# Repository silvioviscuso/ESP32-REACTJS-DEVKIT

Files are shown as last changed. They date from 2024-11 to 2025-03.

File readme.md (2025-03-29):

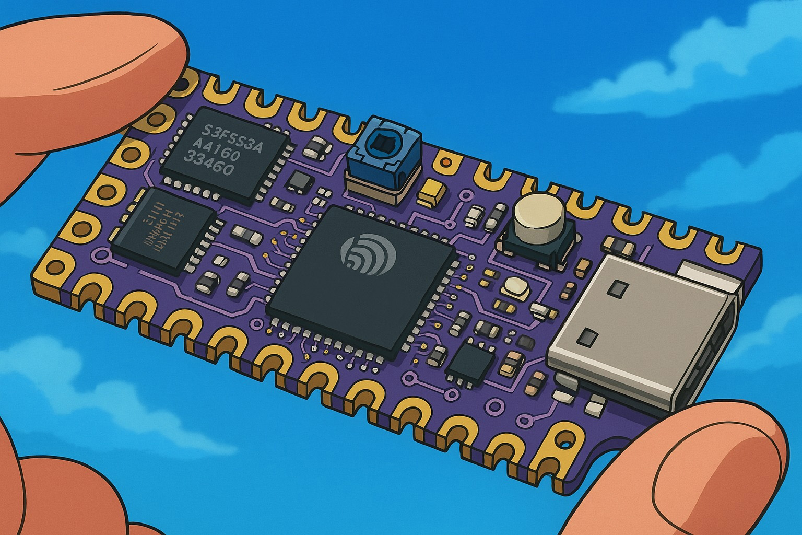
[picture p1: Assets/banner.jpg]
ESP32-REACTJS-DEVKIT


# ESP32-REACTJS-DEVKIT

## 📖 Description
**ESP32-REACTJS-DEVKIT** is an ultra-compact board based on **ESP32-D0WDQ6** with **16MB of Flash RAM**, designed for **robotics, IoT, and wearable** applications. Thanks to its small size and the power of the ESP32, it is ideal for advanced projects requiring wireless connectivity and high computational performance.

### 📏 Dimensions
- **Width:** 35mm  
- **Height:** 18mm  
- **Thickness:** 1mm  

## ⭐ Main Features
- **Microcontroller:** ESP32-D0WDQ6
- **Flash Memory:** 16MB
- **Wi-Fi & Bluetooth:** Dual-mode Wi-Fi and Bluetooth 4.2 BLE
- **Ultra-compact size**, ideal for embedded projects
- **High performance** for advanced applications
- **Support for ESP-IDF and Arduino Framework**

## 🔧 Applications
- **🤖 Robotic Projects**: Motor control, sensors, and actuators with remote connectivity
- **🌐 IoT (Internet of Things)**: Smart home, industrial automation, environmental monitoring
- **⌚ Wearable Devices**: Fitness, health, and human interaction devices

---
## Preview
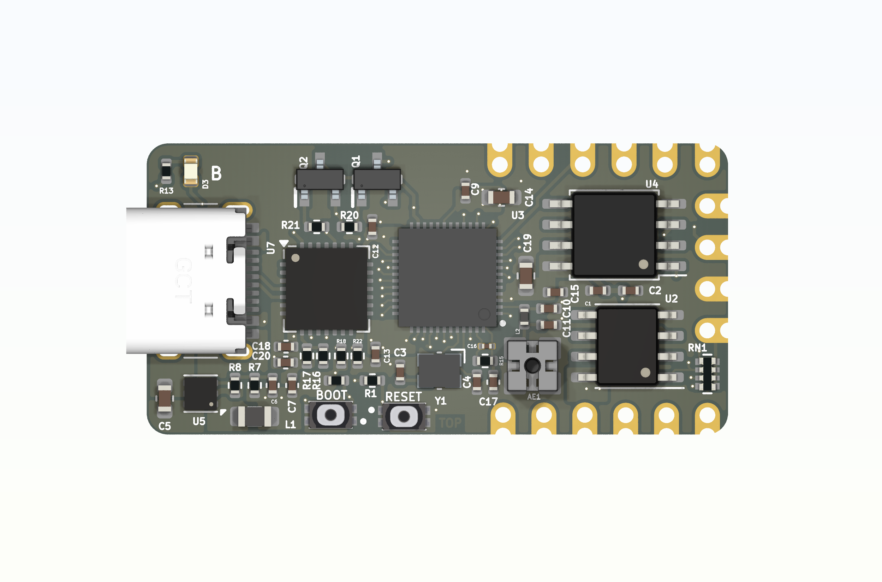
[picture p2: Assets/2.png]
Preview 2

---

## 🛠️ Requirements
- **Software**:
  - ESP-IDF (Espressif IoT Development Framework)
  - Arduino IDE (optional)
  - ReactJS for the frontend management interfaces
- **Hardware**:
  - ESP32-REACTJS-DEVKIT
  - Connection cables
  - Optional sensors and actuators

## 🏗️ Installation
### 1. 🖥️ Development Environment Setup
A **boilerplate** will soon be available to seamlessly integrate with the board. Stay tuned for updates!

### 2. 🌍 ReactJS Frontend Setup
A **dedicated boilerplate** for the ReactJS frontend is in development and will be released soon to simplify integration with the board.

## 🤝 Contributions
If you wish to contribute to the project, feel free to submit a Pull Request or report any issues in the Issues section.

## 📜 License
This project is released under the **MIT** license. You are free to use it with the obligation to credit the original authors.

---

Thank you for choosing **ESP32-REACTJS-DEVKIT**! 🚀

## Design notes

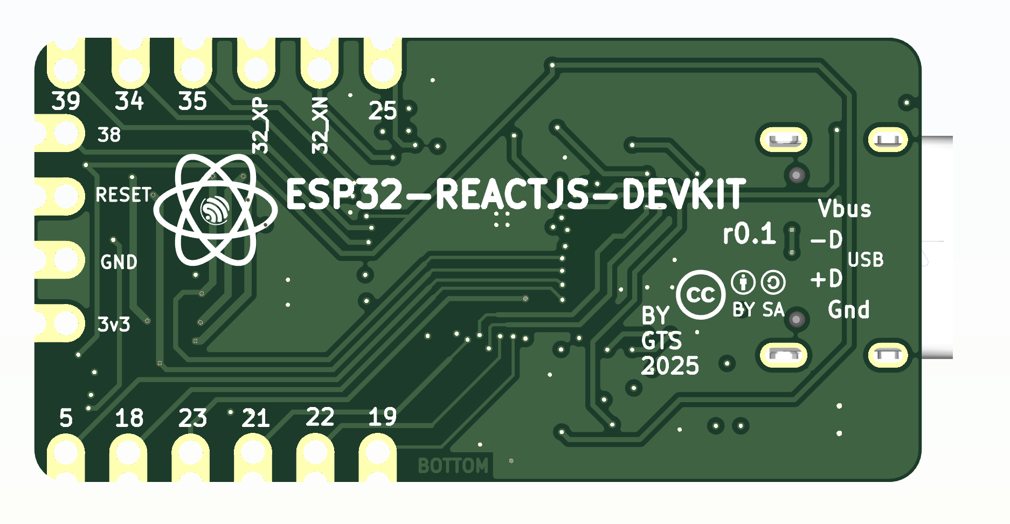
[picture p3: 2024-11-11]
Assets/Preview 2024-11-06 alle 11.08.45.png

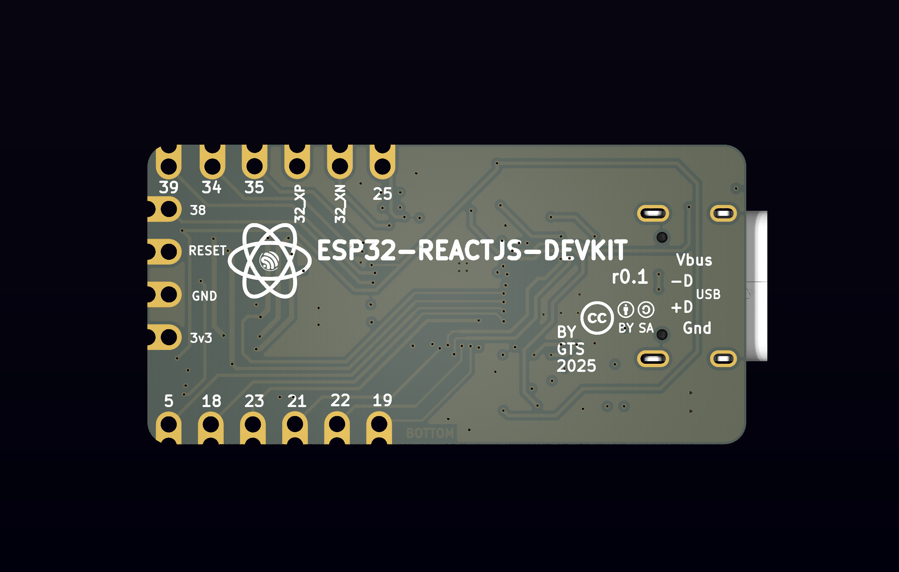
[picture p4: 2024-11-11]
Assets/Preview 2024-11-06 alle 11.10.00.png

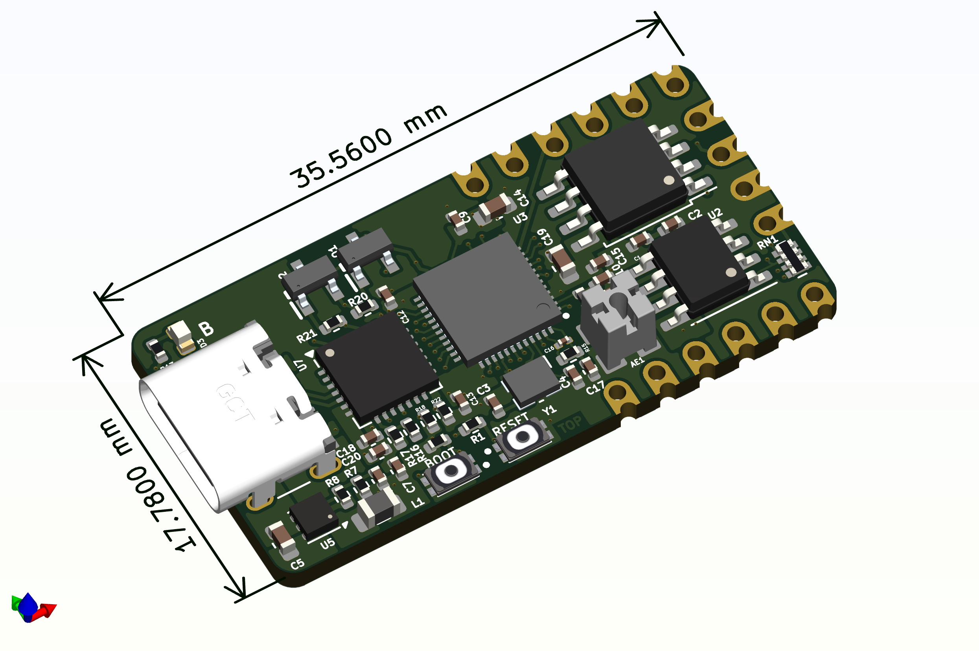
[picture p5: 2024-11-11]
Assets/Preview 2024-11-06 alle 11.07.49.png

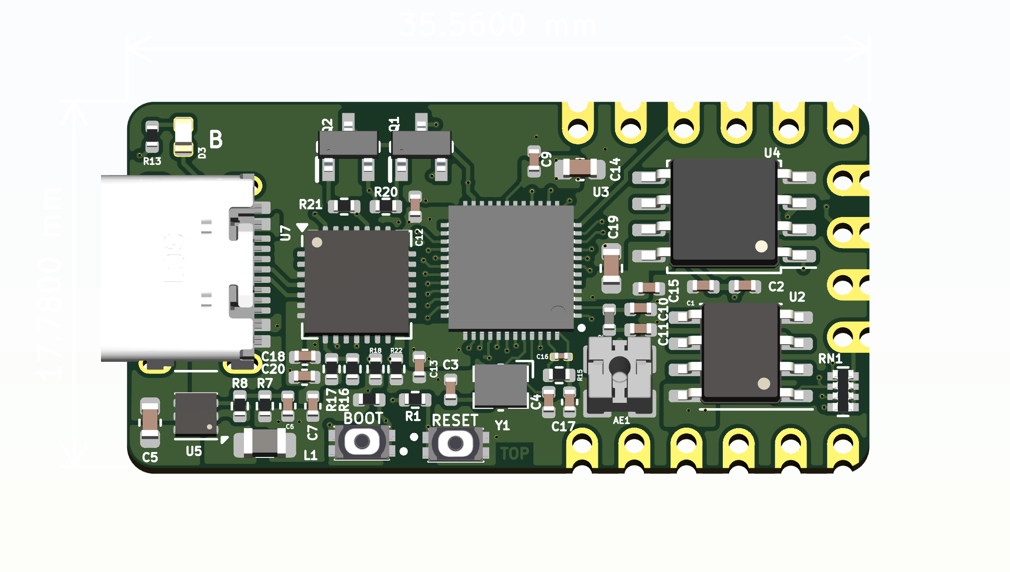
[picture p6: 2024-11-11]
Assets/Preview 2024-11-06 alle 10.54.00.png

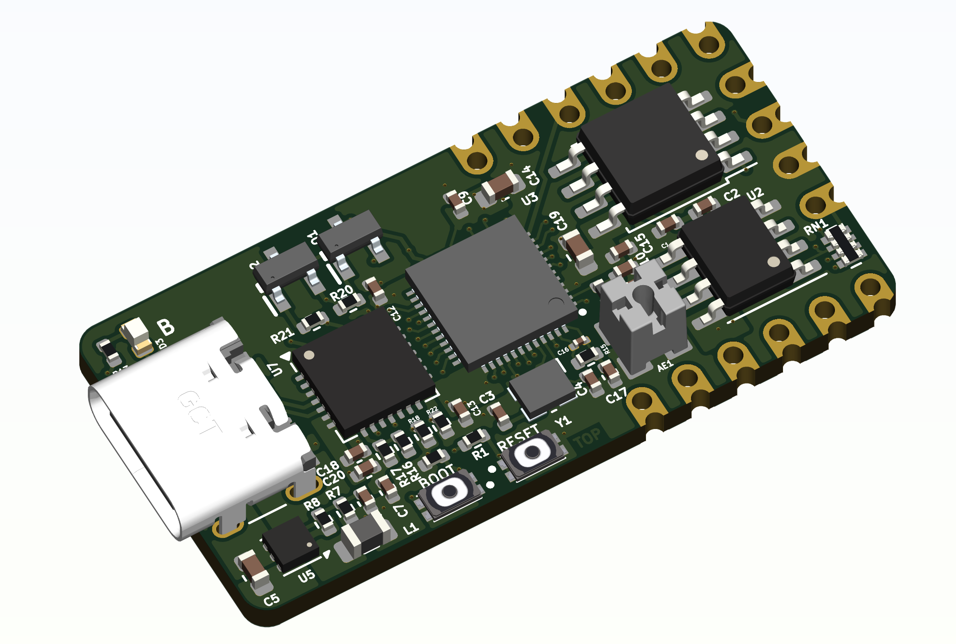
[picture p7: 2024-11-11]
Assets/Preview 2024-11-06 alle 11.07.58.png

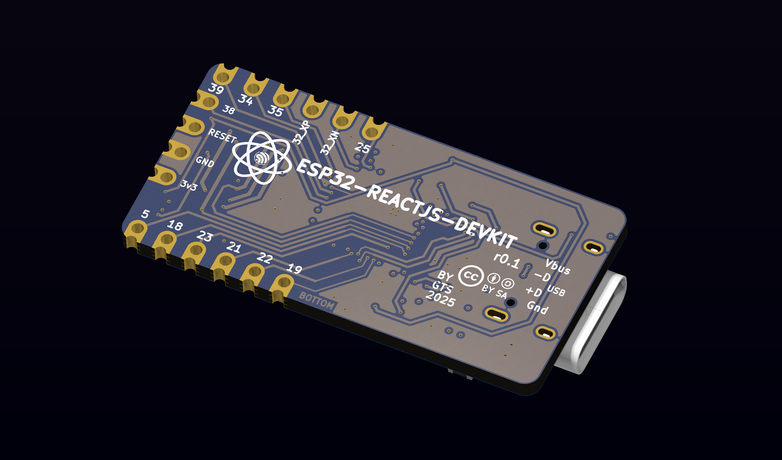
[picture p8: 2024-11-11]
Assets/Preview 2024-11-06 alle 11.17.09.png

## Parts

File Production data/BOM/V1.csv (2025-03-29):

Designator | Value | Footprint | Qty | Mfg | PN | JLCPCB part#
AE1 | Antenna | obsidian-boa:479480001 | 1 | Molex | 479480001 | C152351
C1,C2,C7 | 2.2uF | C_0402_1005Metric | 3 | Yageo | CC0402MRX5R5BB225 | C106860
C3,C4 | 18pF | Capacitor_SMD:C_0402_1005Metric | 2 | Yageo | CC0402GRNPO9BN180 | C114393
C5,C14,C19 | 10u | Capacitor_SMD:C_0603_1608Metric | 3 | Yageo | CC0603KRX5R5BB106 | C109455
C6 | 22pF | Capacitor_SMD:C_0402_1005Metric | 1 | Yageo | CC0402KRNPO9BN220 | C2168187
C9,C12,C13,C15 | 100n | Capacitor_SMD:C_0402_1005Metric | 4 | Yageo | CC0402ZRY5V7BB104 | C106209
C10,C11 | 1pF | Capacitor_SMD:C_0402_1005Metric | 2 |  | CQ0402CRNPO9BN1R0 | C1550
C16 | 3.3nF | Capacitor_SMD:C_0201_0603Metric | 1 | Yageo | GRM033R70J332KA01D | C312053
C17 | 10nF | Capacitor_SMD:C_0402_1005Metric | 1 | Yageo | KGM05AR70J103KH | C60133
C18 | 0.1uF | Capacitor_SMD:C_0402_1005Metric | 1 | Yageo | CL05B104KP5NNNC | C133086
C20 | 4.7uF | Capacitor_SMD:C_0402_1005Metric | 1 | Yageo | CL05A475MP5NRNC | C23733
D3 | BLU | obsidian-boa:LED_0603_1608Metric_Compact | 1 | Lite-On Inc. | LTST-C191TBKT | C99290
J1 | USB_C | V1-foot:USB_C_Receptacle_HRO_TYPE-C-31-M-12 | 1 | GCT | USB4105-GF-A | C3025063
L1 | 2.2uH | Inductor_SMD:L_0805_2012Metric | 1 |  | CWCI0805F-100KT | C1043
L2 | 2.7nH | Inductor_SMD:L_0402_1005Metric | 1 |  | SDCL1005C2N7STDF | C27123
Q1,Q2 | SS8050-G | SOT95P240X115-3N | 2 |  | SS8050-G | C164885
RN1 | 10K | Resistor_SMD:R_Array_Convex_4x0402 | 1 |  |  | C178757
R1,R10 | 10k | Resistor_SMD:R_0402_1005Metric | 3 | -- mixed values -- | -- mixed values -- | C60490
R7 | 453k | Resistor_SMD:R_0402_1005Metric | 1 | Yageo | RC0402FR-07453KL | C137978
R8 | 100k | Resistor_SMD:R_0402_1005Metric | 1 | Yageo | RC0402FR-07100KL | C60491
R13 | 2k2 | Resistor_SMD:R_0402_1005Metric | 1 | Yageo | RC0402FR-072K2L | C114762
R15 | 20K | Resistor_SMD:R_0402_1005Metric | 1 | Yageo | RC0402FR-0720KL | C93942
R16 | 22.1K | Resistor_SMD:R_0402_1005Metric | 1 | Yageo | CRCW040222K1FKEDC | C43473
R17 | 47.5K | Resistor_SMD:R_0402_1005Metric | 1 | Yageo | RC0402FR-0747K5L | C137974
R18 | 2K | Resistor_SMD:R_0402_1005Metric | 1 | Yageo | ERJ-2RKF2001X | C413086
R20,R21,R22 | 10K | Resistor_SMD:R_0402_1005Metric | 3 | Yageo | RC0402FR-0710KL | C60490
SW1,SW2 | TACT | CP2102:EVPBB2A9B000 | 2 |  | EVP-BB2A9B000 | C9900011190
U2 | LY68L6400SLIT | Package_SO:SOIC-8_3.9x4.9mm_P1.27mm | 1 |  | LY68L6400SLIT | C261881
U3 | ESP32-D0WDQ6 | V1-foot:QFN40P600X600X90-49N-D | 1 |  | ESP32-D0WDQ6 | C129733
U4 | W25Q128JV | Package_SO:SOIC-8_5.23x5.23mm_P1.27mm | 1 | Winbond Electronics | W25Q128JVSIQ TR | C97521
U5 | TPS62290 | Package_SON:WSON-6-1EP_2x2mm_P0.65mm_EP1x1.6mm_ThermalVias | 1 | Texas Instruments | TPS62290DRVR | C129315
U7 | CP2102N-Axx-xQFN28 | Package_DFN_QFN:QFN-28-1EP_5x5mm_P0.5mm_EP3.35x3.35mm | 1 |  | CP2102N-A02-GQFN28R | C964632
Y1 | 40MHz | Crystal:Crystal_SMD_Abracon_ABM10-4Pin_2.5x2.0mm | 1 | ECS Inc. | ECS-400-10-36B-CKY-TR | C6941971

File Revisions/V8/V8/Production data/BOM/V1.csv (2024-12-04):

Reference | Value | Qty | Mfg | PN
AE1 | Antenna | 1 | Molex | 0479480001
C1,C2,C7 | 2.2uF | 3 | Yageo | CC0402MRX5R5BB225
C3,C4 | 18pF | 2 | Yageo | CC0402GRNPO9BN180
C5,C14,C19 | 10u | 3 | Yageo | CC0603KRX5R5BB106
C6 | 22pF | 1 | Yageo | CC0402KRNPO9BN220
C9,C12,C13,C15 | 100n | 4 | Yageo | CC0402ZRY5V7BB104
C10,C11 | 1pF | 2 |  | CQ0402CRNPO9BN1R0
C16 | 3.3nF | 1 | Yageo | GRM033R70J332KA01D
C17 | 10nF | 1 | Yageo | KGM05AR70J103KH
C18 | 0.1uF | 1 | Yageo | CL05B104KP5NNNC
C20 | 4.7uF | 1 | Yageo | CL05A475MP5NRNC
D3 | BLU | 1 | Lite-On Inc. | LTST-C191TBKT
J1 | USB_C | 1 | GCT | USB4105-GF-A
L1 | 2.2uH | 1 |  | CWCI0805F-100KT
L2 | 2.7nH | 1 |  | SDCL1005C2N7STDF
P7 | 7 | 1
P8 | 8 | 1
P9 | 9 | 1
P10 | 10 | 1
P11 | 11 | 1
P12 | 12 | 1
P13 | 13 | 1
P14 | 14 | 1
P16 | 16 | 1
P17 | 17 | 1
P18 | 18 | 1
P25 | GND | 1
P28 | 3V3 | 1
P30 | CDONE | 1
P31 | CRESET | 1
Q1,Q2 | SS8050-G | 2 |  | SS8050-G
R1,R10,RN1 | 10k | 3 | -- mixed values -- | -- mixed values --
R7 | 453k | 1 | Yageo | RC0402FR-07453KL
R8 | 100k | 1 | Yageo | RC0402FR-07100KL
R13 | 2k2 | 1 | Yageo | RC0402FR-072K2L
R15 | 20K | 1 | Yageo | RC0402FR-0720KL
R16 | 22.1K | 1 | Yageo | CRCW040222K1FKEDC
R17 | 47.5K | 1 | Yageo | RC0402FR-0747K5L
R18 | 2K | 1 | Yageo | ERJ-2RKF2001X
R20,R21,R22 | 10K | 3 | Yageo | RC0402FR-0710KL
SW1,SW2 | TACT | 2 |  | EVP-BB2A9B000
U2 | LY68L6400SLIT | 1 |  | LY68L6400SLIT
U3 | ESP32-D0WDQ6 | 1 |  | ESP32-D0WDQ6
U4 | W25Q128JV | 1 | Winbond Electronics | W25Q128JVSIQ TR
U5 | TPS62290 | 1 | Texas Instruments | TPS62290DRVR
U7 | CP2102N-Axx-xQFN28 | 1 |  | CP2102N-A02-GQFN28R
Y1 | 40MHz | 1 | ECS Inc. | ECS-400-10-36B-CKY-TR

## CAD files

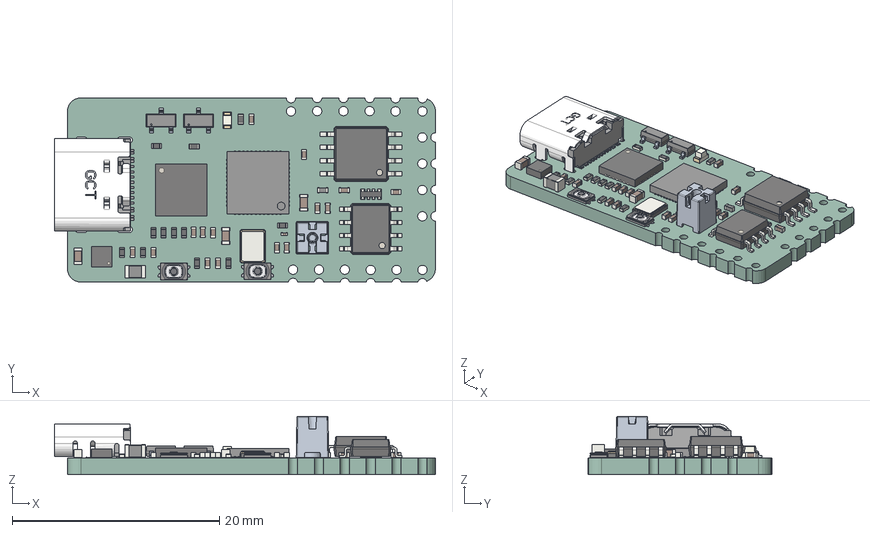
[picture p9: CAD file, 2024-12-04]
Production data/STEP/V1.step
36.8 x 17.8 x 5.65 mm
root x 2
LED_0603_1608Metric
C_0402_1005Metric x 15
USB4105-GF-A-120
C_0603_1608Metric x 3
R_0402_1005Metric x 12
QFN-28-1EP_5x5mm_Pitch0.5mm
WSON_6_1EP_2x2mm_P065mm_EP1x16mm
SOIC_8_5275x5275mm_P127mm
ASSEMBLY x 3
R_Array_Convex_4x0402
L_0402_1005Metric
Crystal_SMD_Abracon_ABM8G-4Pin_3.2x2.5mm
L_0805_2012Metric
SOIC_8_39x49mm_P127mm
C_0201_0603Metric
V1_PCB

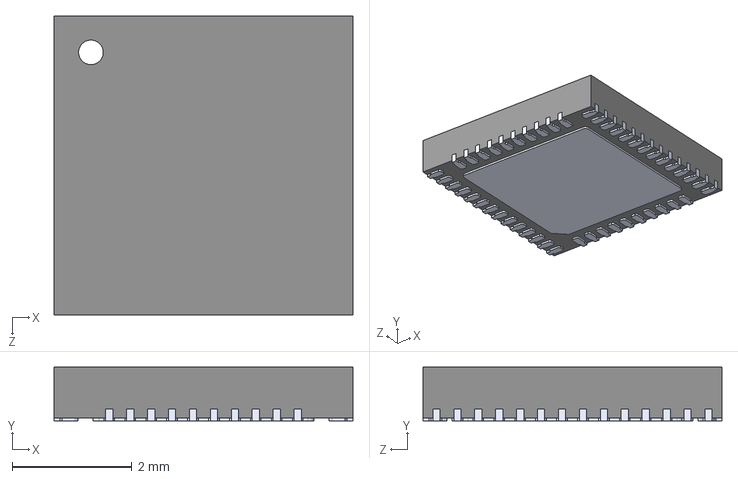
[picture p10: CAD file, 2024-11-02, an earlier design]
Revisions/V1/ESP32-D0WD.step
5.00 x 0.9 x 5.00 mm

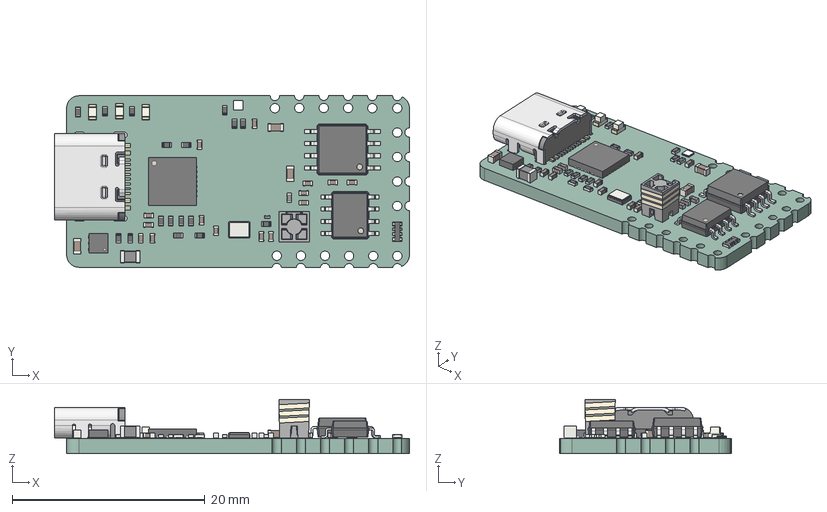
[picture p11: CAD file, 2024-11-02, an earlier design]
Revisions/V1/Production Data/3D_step file.step
36.8 x 17.8 x 5.65 mm
LED_0603_1608Metric x 3
C_0402_1005Metric x 15
ConPins
PcbPins
Mold
Frame
C_0603_1608Metric x 3
R_0402_1005Metric x 17
(Unsaved)
QFN-28-1EP_5x5mm_Pitch0.5mm
WSON_6_1EP_2x2mm_P065mm_EP1x16mm
SOIC_8_5275x5275mm_P127mm
R_Array_Convex_4x0402
L_0402_1005Metric
Crystal_SMD_EuroQuartz_MT-4Pin_3.2x2.5mm
L_0805_2012Metric
SOIC_8_39x49mm_P127mm
C_0201_0603Metric
obsidian-boa-r0.1_PCB

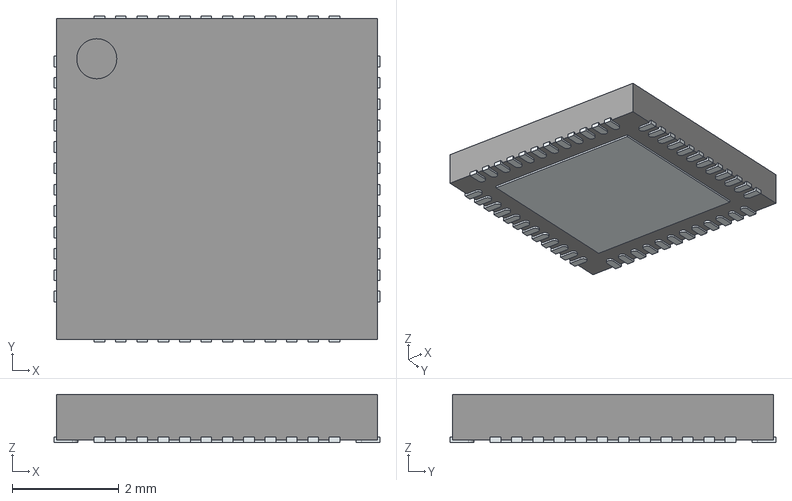
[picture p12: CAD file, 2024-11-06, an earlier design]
Revisions/V3/ESP32-D0WDQ6.stp
6.10 x 6.10 x 0.9 mm
ThermalPin
PinsArrayLR
PinsArrayTB

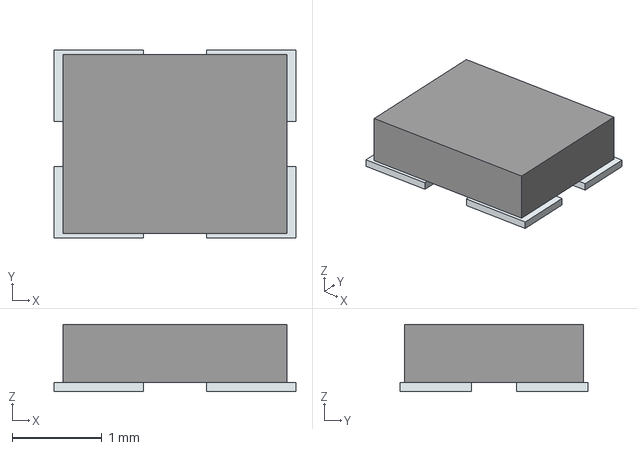
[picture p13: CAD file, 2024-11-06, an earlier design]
Revisions/V4/ECS-400-10-36B-CKY-TR.stp
2.70 x 2.10 x 0.75 mm
Pins

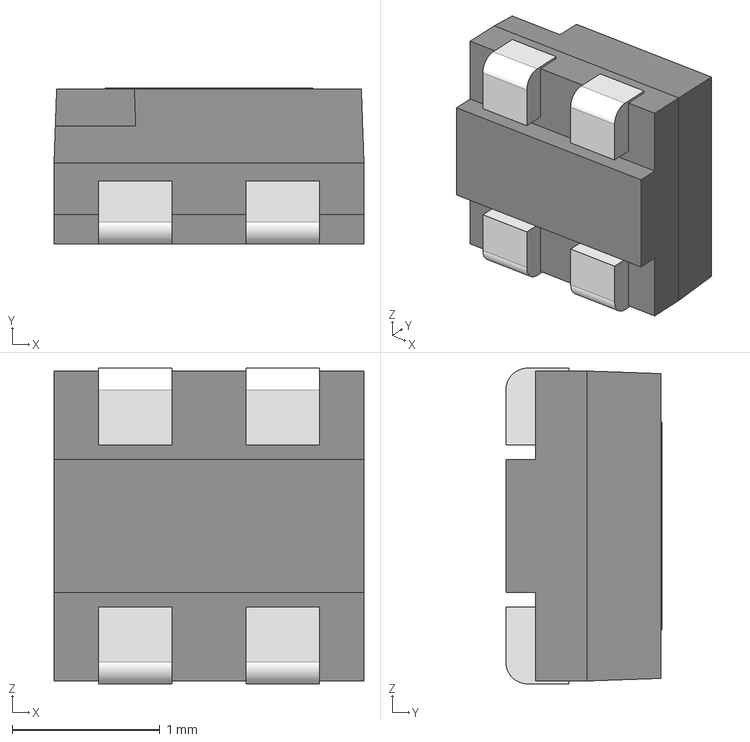
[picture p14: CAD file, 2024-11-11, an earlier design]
Revisions/V5/V5/FOSHAN-FM-B2020RGBA-HG.stp
2.10 x 1.06 x 2.14 mm

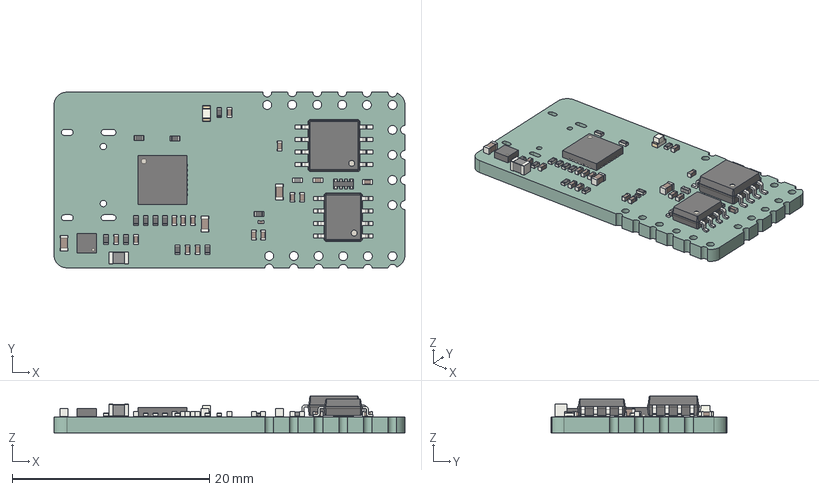
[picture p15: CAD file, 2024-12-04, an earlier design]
Revisions/V7/V1/Production data/STEP/V1.step
35.6 x 17.8 x 3.71 mm
LED_0603_1608Metric
C_0402_1005Metric x 15
C_0603_1608Metric x 3
R_0402_1005Metric x 12
QFN-28-1EP_5x5mm_Pitch0.5mm
WSON_6_1EP_2x2mm_P065mm_EP1x16mm
SOIC_8_5275x5275mm_P127mm
R_Array_Convex_4x0402
L_0402_1005Metric
L_0805_2012Metric
SOIC_8_39x49mm_P127mm
C_0201_0603Metric
_autosave-V1_PCB

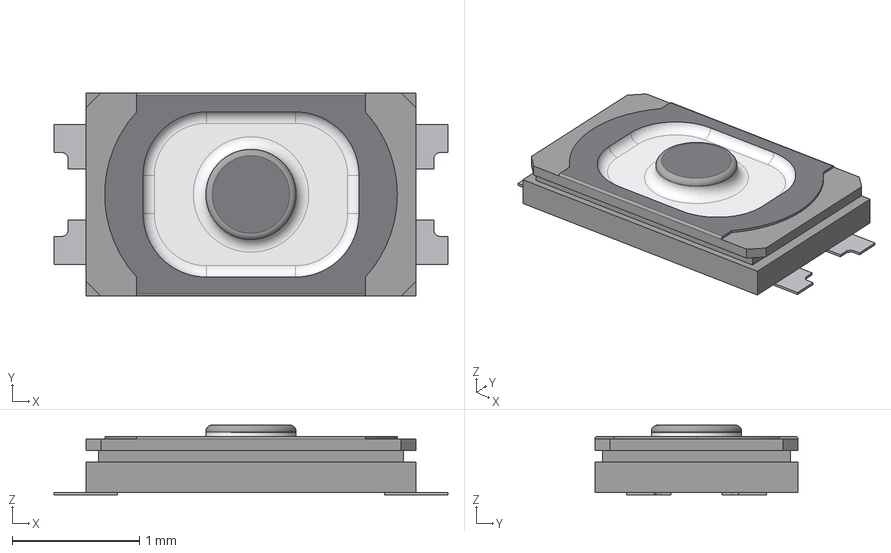
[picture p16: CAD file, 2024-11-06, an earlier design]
Revisions/V3/EVP-BB2A9B000.stp
3.10 x 1.60 x 0.55 mm

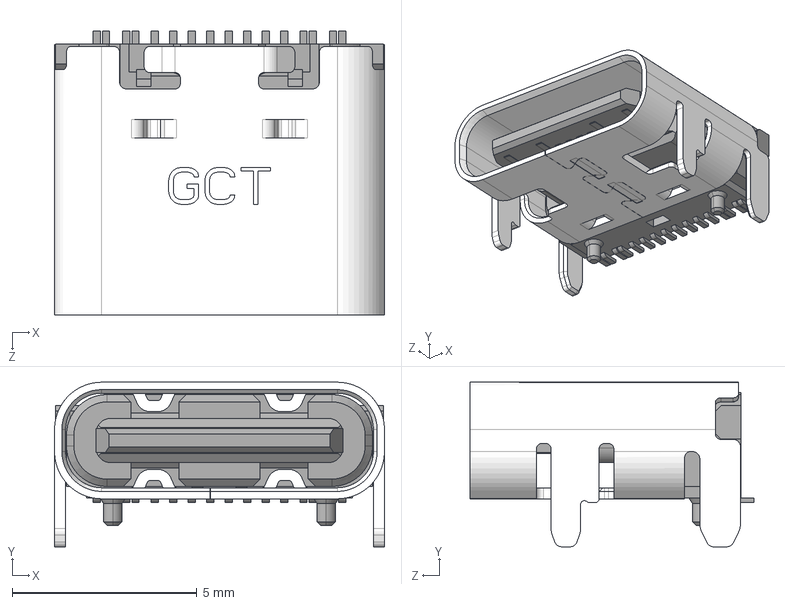
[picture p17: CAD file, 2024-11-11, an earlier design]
Revisions/V6/V5/USB4105-GF-A-120.stp
8.94 x 4.46 x 7.70 mm
USB4105-15-A-120_PART2^USB4105-15-A-120(2)_USB4105-15-A-120
USB4105-15-A-120_PART1^USB4105-15-A-120(2)_USB4105-15-A-120

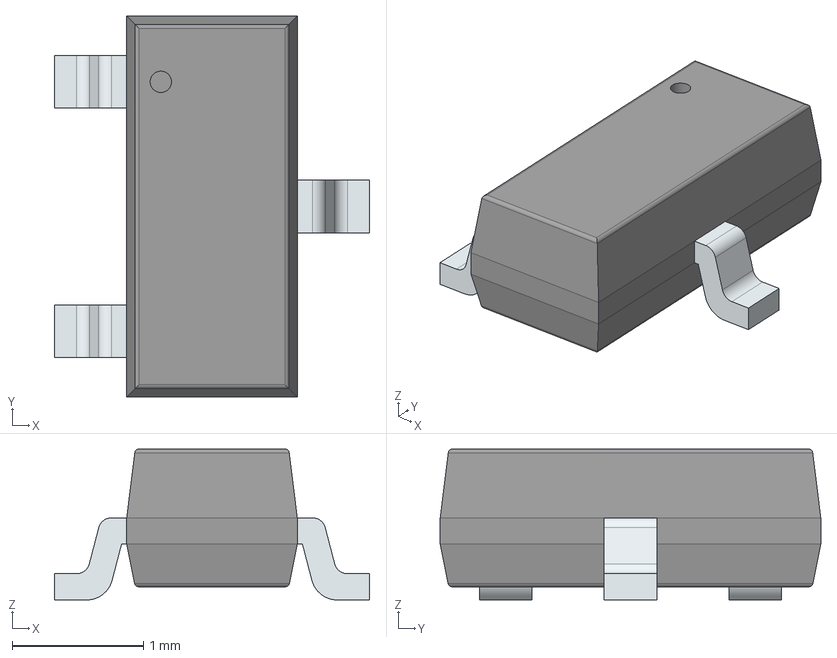
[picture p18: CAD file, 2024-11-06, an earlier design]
Revisions/V3/SS8050-G.stp
2.40 x 2.90 x 1.15 mm
PinsArrayL
FilletPinR

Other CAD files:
Revisions/V6/V5/ESP32-D0WD.step
Revisions/V4/FOSHAN-FM-B2020RGBA-HG.stp
Revisions/V5/V5/ESP32-D0WD.step
Revisions/V4/step.step
Revisions/V4/47948-0001.stp
Revisions/V4/USB4105-GF-A-120.stp
Revisions/V4/black_blue.step
Revisions/V5/V5/47948-0001.stp
Revisions/V5/V5/EVP-BB2A9B000.stp
Revisions/V5/V5/black_blue.step
Revisions/V5/V5/step.step
Revisions/V6/V5/47948-0001.stp
Revisions/V6/V5/EVP-BB2A9B000.stp
Revisions/V6/V5/black_blue.step
Revisions/V6/V5/step.step

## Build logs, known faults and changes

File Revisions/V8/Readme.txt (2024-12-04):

files 

in folder files are managed like this
1) client requirement file
	
	this file contains files which you send me for project

2) Deliverables

	in this i generally add gerber and NC drill file but you will get these file in next 	folder

3) PCB
	this file contains all project file, libraries, production data

	subfolders
	a) lib-  in this folder you will get components symbol and footprint library and also 		3D
	b) production data- 
		this folder contains these files
		BOM,DRC report, NCdrill , gerber, Pick&place,schematic,step, files

	c) apart from this you will get kicad project file in the folder just double click on 		file V1.kicad project file all files will automatically open in kicad

work which i made in PCB
1) Schematics
	some of the components are mapped wrongly
	pin map
	exact symbol matching

2) library
	created footprint and 3D library for components which are not previously included

3) PCB routing

	Changes in via size
	silkscreen text resize and alignment

..............................................

in this file deliverables-03-12-24
these are the changes

1)footprint pad size shorten
2) spi via correct
3) exit slope of esp
4) usb shield connnection

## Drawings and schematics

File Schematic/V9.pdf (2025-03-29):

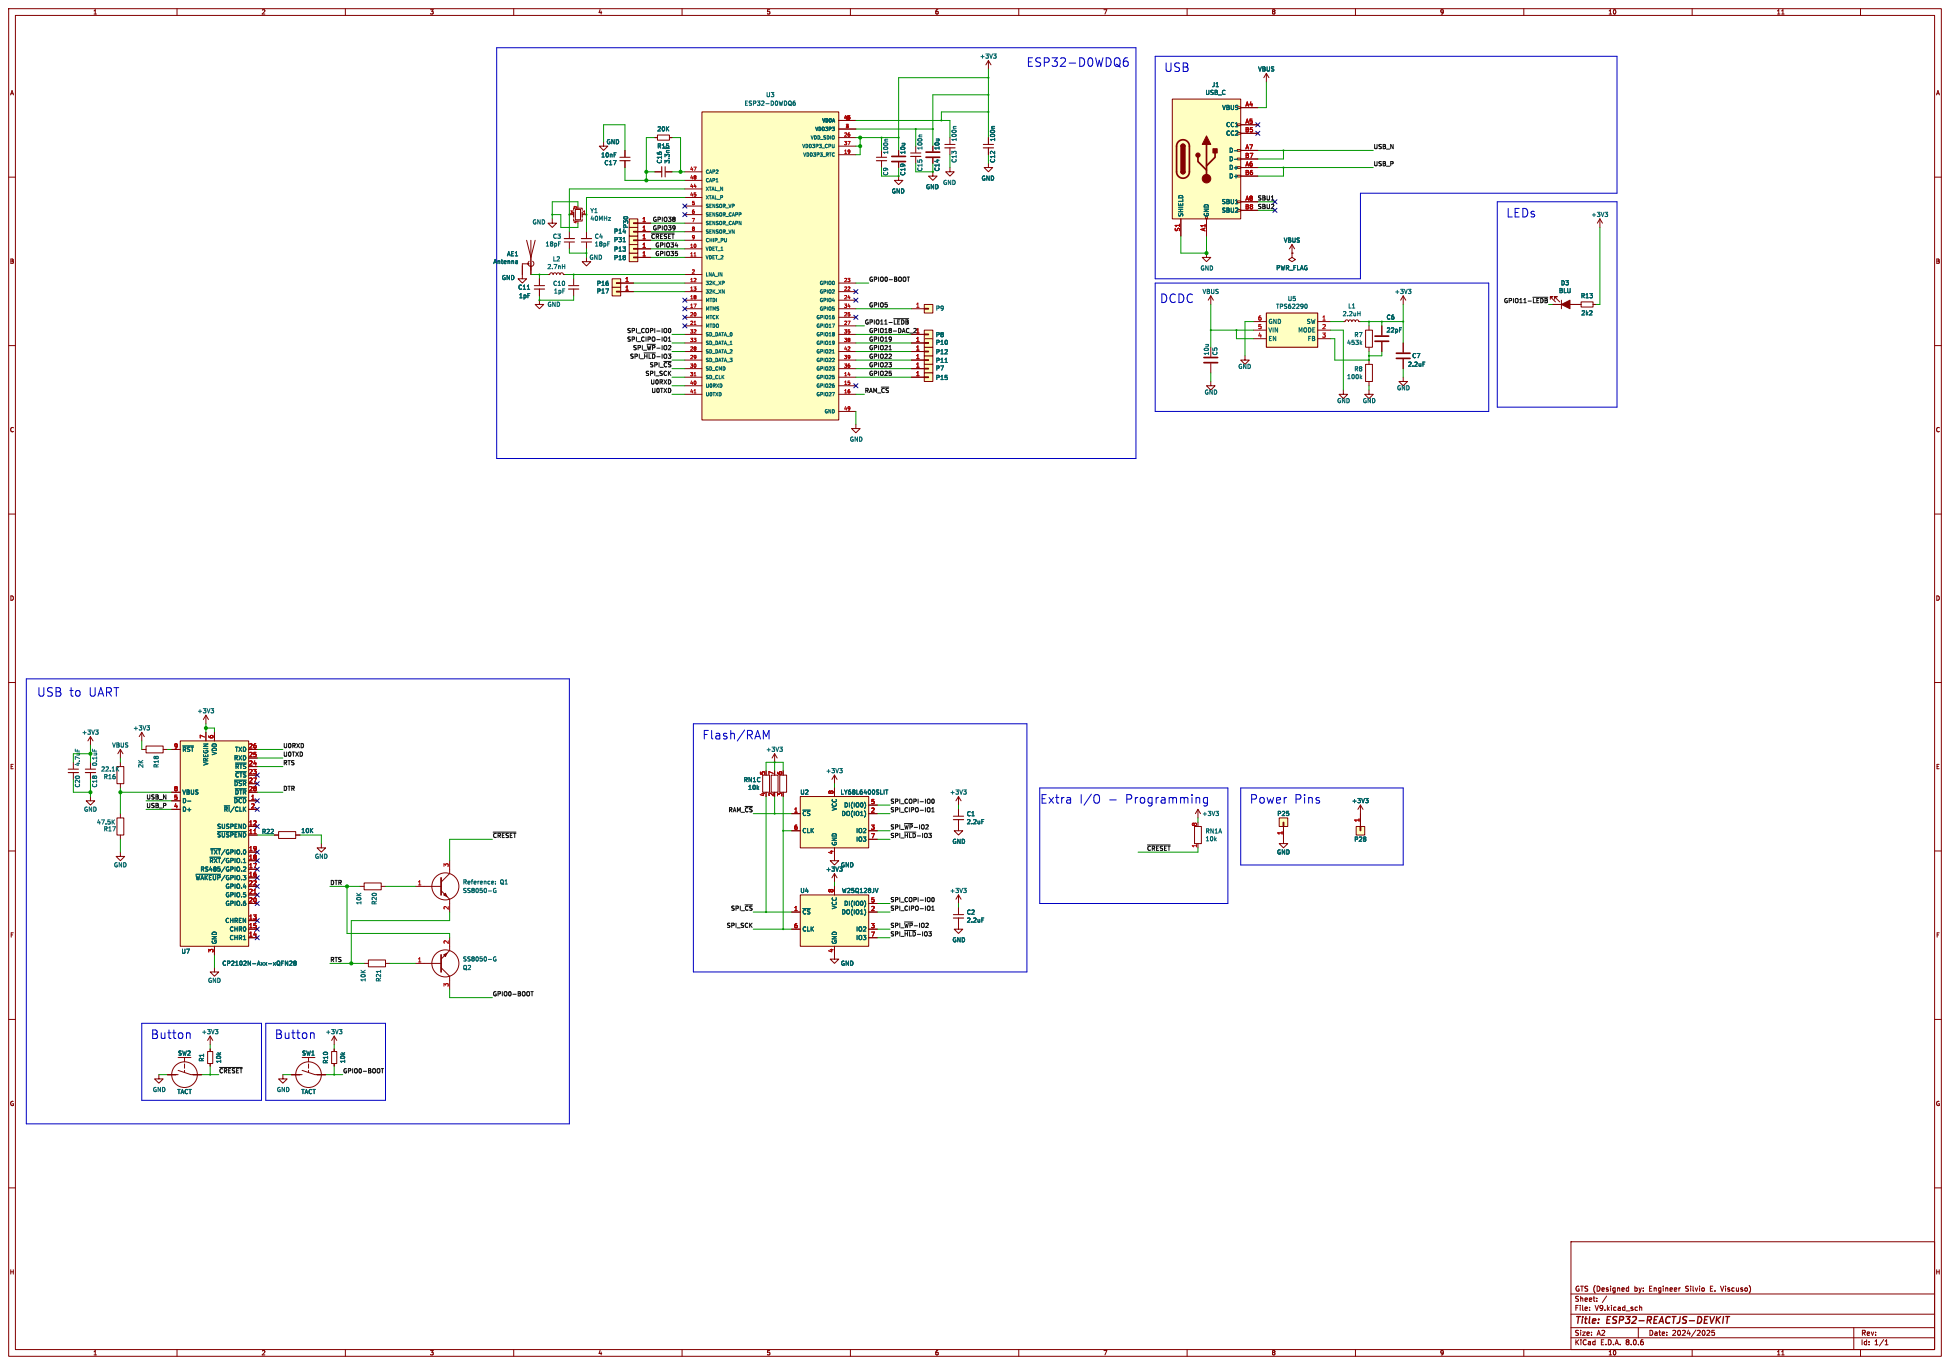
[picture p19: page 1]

SPI_~{HLD}-IO3 SPI_COPI-IO0 USB to UART

7 VBUS 8 ~{RST} 9 U7 CP2102N-Axx-xQFN28 GND C20 4.7uF

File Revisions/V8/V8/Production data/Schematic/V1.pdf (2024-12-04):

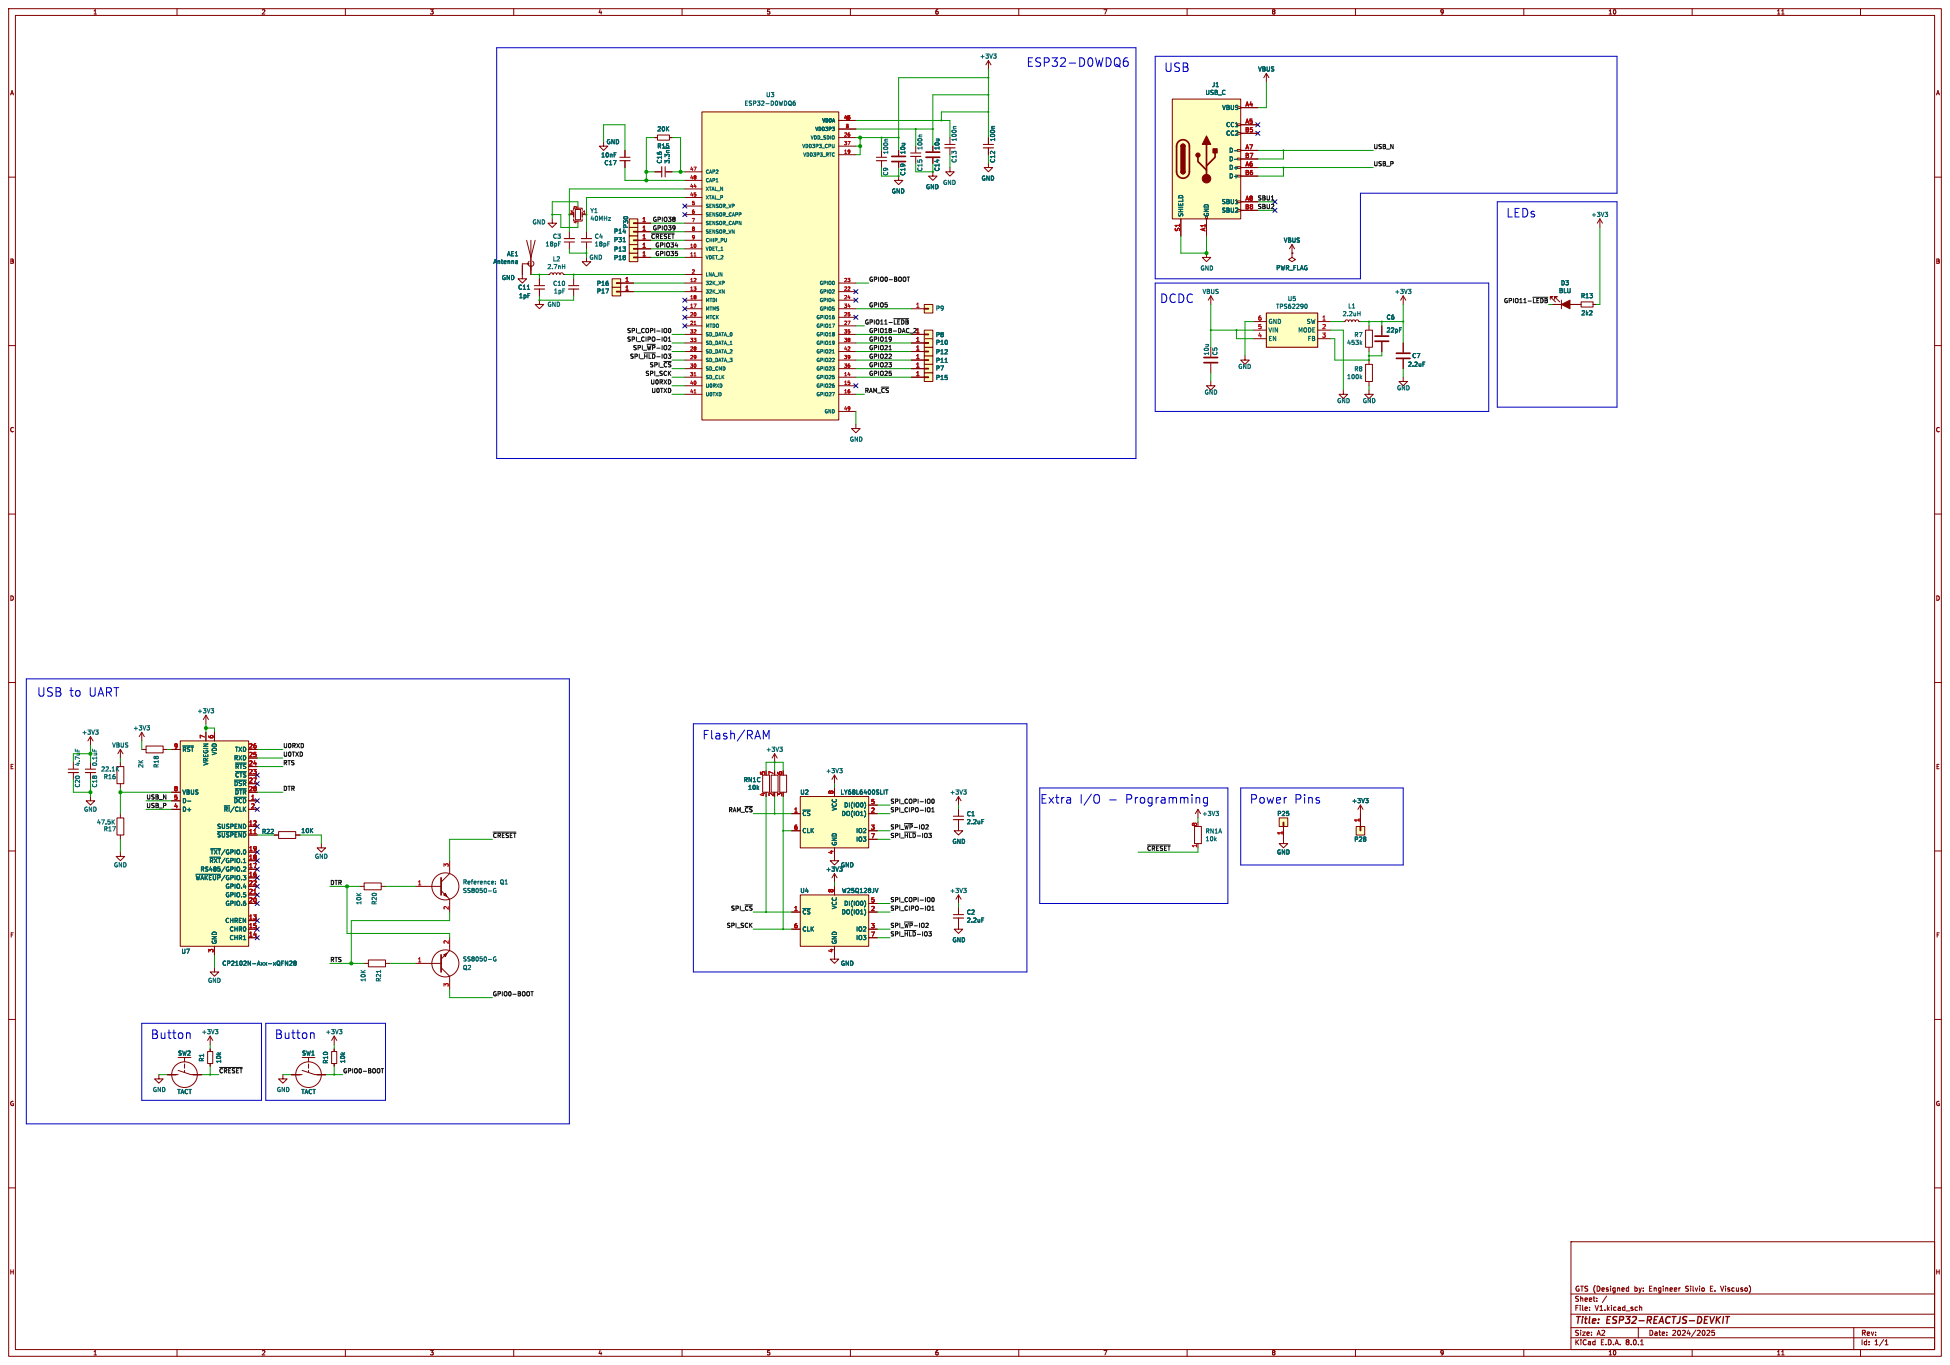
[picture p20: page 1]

7 VBUS 8 ~{RST} 9 U7 CP2102N-Axx-xQFN28 SW2 GND TACT

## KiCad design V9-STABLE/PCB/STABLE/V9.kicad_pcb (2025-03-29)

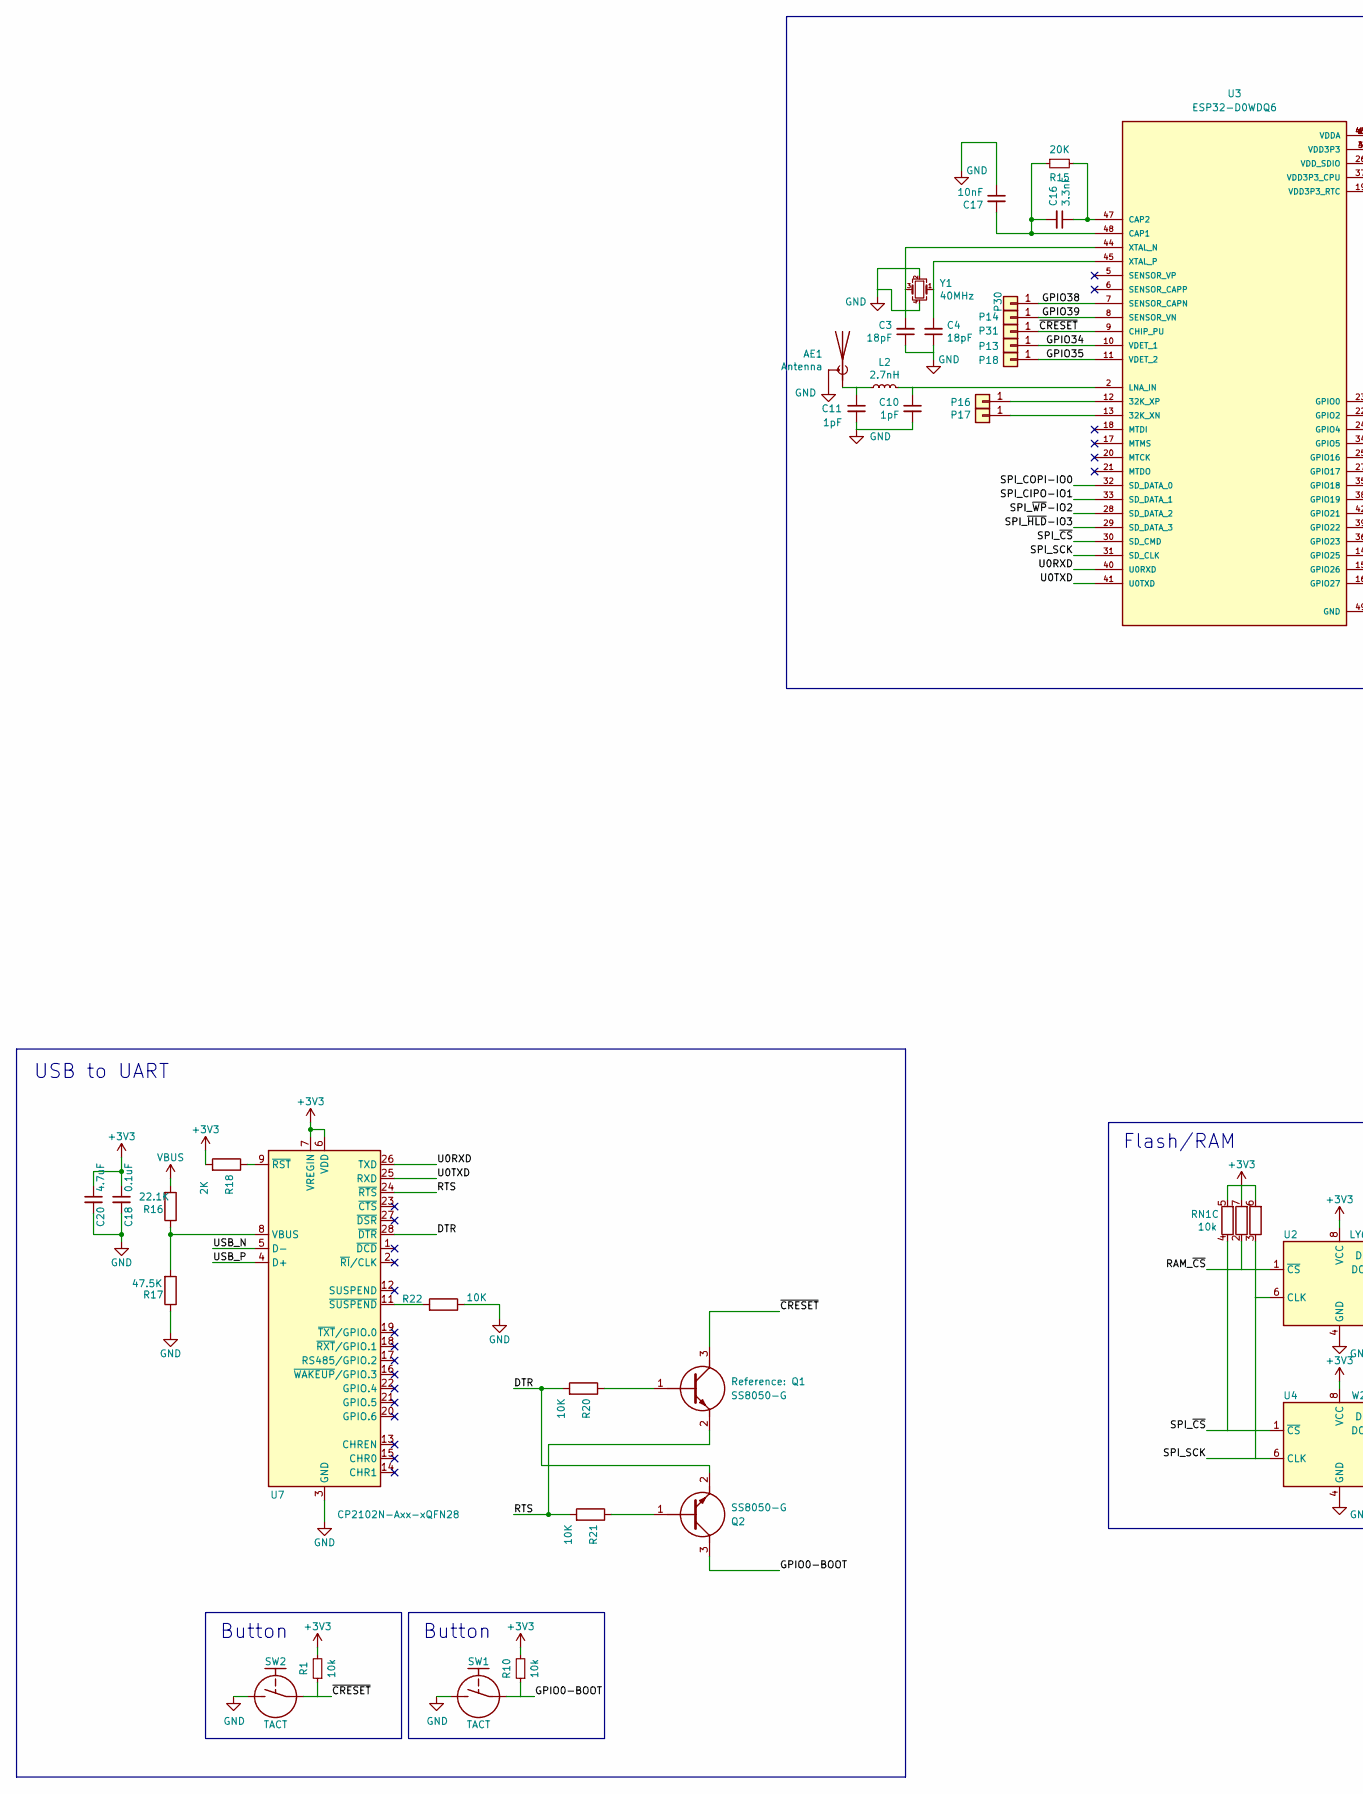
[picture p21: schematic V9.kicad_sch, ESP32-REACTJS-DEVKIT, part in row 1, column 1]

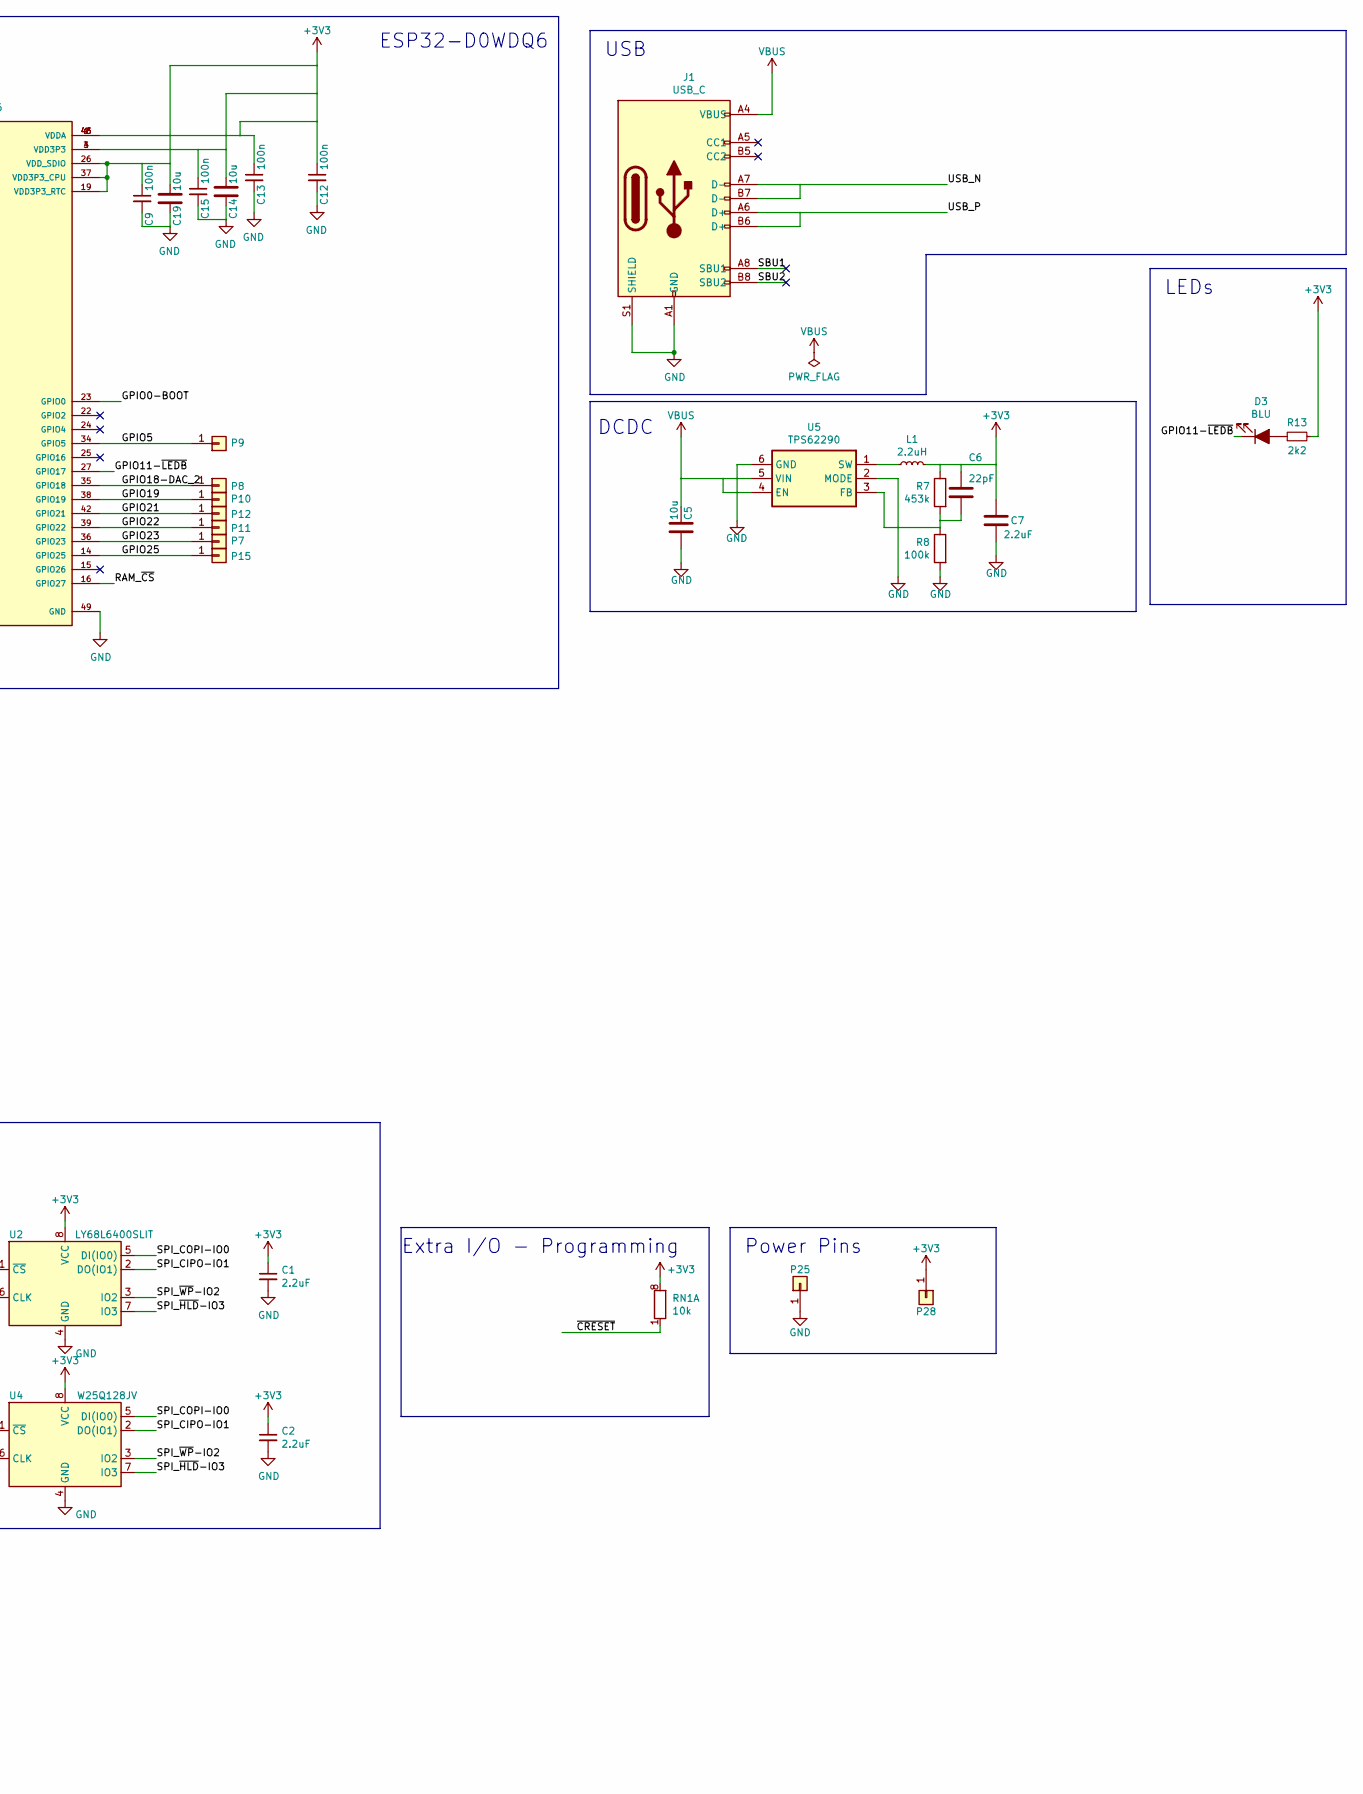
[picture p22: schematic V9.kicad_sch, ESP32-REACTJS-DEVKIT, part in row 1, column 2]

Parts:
AE1: Antenna; 479480001.stp
C1, C2, C7: 2.2uF; C_0402_1005Metric
C3, C4: 18pF; C_0402_1005Metric
C5, C14, C19: 10u; C_0603_1608Metric
C6: 22pF; C_0402_1005Metric
C9, C12, C13, C15: 100n; C_0402_1005Metric
C10, C11: 1pF; C_0402_1005Metric
C16: 3.3nF; C_0201_0603Metric
C17: 10nF; C_0402_1005Metric
C18: 0.1uF; C_0402_1005Metric
C20: 4.7uF; C_0402_1005Metric
D3: BLU; LED_0603_1608Metric_Compact
J1: USB_C; USB_C_Receptacle_HRO_TYPE-C-31-M-12
L1: 2.2uH; L_0805_2012Metric
L2: 2.7nH; L_0402_1005Metric
P7: 7; Pin_Header_Straight_Round_1x01_Castellated
P8: 8; Pin_Header_Straight_Round_1x01_Castellated
P9: 9; Pin_Header_Straight_Round_1x01_Castellated
P10: 10; Pin_Header_Straight_Round_1x01_Castellated
P11: 11; Pin_Header_Straight_Round_1x01_Castellated
P12: 12; Pin_Header_Straight_Round_1x01_Castellated
P13: 13; Pin_Header_Straight_Round_1x01_Castellated
P14: 14; Pin_Header_Straight_Round_1x01_Castellated
P15: 15; Pin_Header_Straight_Round_1x01_Castellated
P16: 16; Pin_Header_Straight_Round_1x01_Castellated
P17: 17; Pin_Header_Straight_Round_1x01_Castellated
P18: 18; Pin_Header_Straight_Round_1x01_Castellated
P25: GND; Pin_Header_Straight_Round_1x01_Castellated
P28: 3V3; Pin_Header_Straight_Round_1x01_Castellated
P30: CDONE; Pin_Header_Straight_Round_1x01_Castellated
P31: CRESET; Pin_Header_Straight_Round_1x01_Castellated
Q1, Q2: SS8050-G; SOT95P240X115-3N; Mouser Part Number 750-SS8050-G
R1, R10: 10k; R_0402_1005Metric
R7: 453k; R_0402_1005Metric
R8: 100k; R_0402_1005Metric
R13: 2k2; R_0402_1005Metric
R15: 20K; R_0402_1005Metric
R16: 22.1K; R_0402_1005Metric
R17: 47.5K; R_0402_1005Metric
R18: 2K; R_0402_1005Metric
R20, R21, R22: 10K; R_0402_1005Metric
RN1: 10k; R_Array_Convex_4x0402
SW1, SW2: TACT; EVPBB2A9B000; MPN EVP-BB2A9B000
U2: LY68L6400SLIT; SOIC-8_3.9x4.9mm_P1.27mm
U3: ESP32-D0WDQ6; QFN40P600X600X90-49N-D; PARTREV 1.7
U4: W25Q128JV; SOIC-8_5.23x5.23mm_P1.27mm
U5: TPS62290; WSON-6-1EP_2x2mm_P0.65mm_EP1x1.6mm_ThermalVias
U7: CP2102N-Axx-xQFN28; QFN-28-1EP_5x5mm_P0.5mm_EP3.35x3.35mm
Y1: 40MHz; Crystal_SMD_Abracon_ABM10-4Pin_2.5x2.0mm

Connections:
+3V3: C1.1, C2.1, C6.1, C7.1, C9.1, C12.1, C13.1, C14.1, C15.1, C18.1, C19.1, C20.1, L1.2, P28.1, R1.2, R7.1, R10.2, R13.2, R18.2, RN1.5 (R4.2), RN1.6 (R3.2), RN1.7 (R2.2), RN1.8 (R1.2), U2.8 (VCC), U3.1 (VDDA), U3.3 (VDD3P3), U3.4 (VDD3P3), U3.19 (VDD3P3_RTC), U3.26 (VDD_SDIO), U3.37 (VDD3P3_CPU), U3.43 (VDDA), U3.46 (VDDA), U4.8 (VCC), U7.6 (VDD), U7.7 (VREGIN)
/DTR: Q2.2 (E), R20.2, U7.28 (~DTR)
/GPIO0-BOOT: Q2.3 (C), R10.1, SW1.1, SW1.2, U3.23 (GPIO0)
/GPIO5: P9.1, U3.34 (GPIO5)
/GPIO11-~LEDB: D3.1 (K), U3.27 (GPIO17)
/GPIO18-DAC_2: P8.1, U3.35 (GPIO18)
/GPIO19: P10.1, U3.38 (GPIO19)
/GPIO21: P12.1, U3.42 (GPIO21)
/GPIO22: P11.1, U3.39 (GPIO22)
/GPIO23: P7.1, U3.36 (GPIO23)
/GPIO25: P15.1, U3.14 (GPIO25)
/GPIO34: P13.1, U3.10 (VDET_1)
/GPIO35: P18.1, U3.11 (VDET_2)
/GPIO38: P30.1, U3.7 (SENSOR_CAPN)
/GPIO39: P14.1, U3.8 (SENSOR_VN)
/RAM_~CS: RN1.2 (R2.1), U2.1 (~CS), U3.16 (GPIO27)
/RTS: Q1.2 (E), R21.2, U7.24 (~RTS)
/SBU1: J1.A8 (SBU1)
/SBU2: J1.B8 (SBU2)
/SPI_CIPO-IO1: U2.2 (DO(IO1)), U3.33 (SD_DATA_1), U4.2 (DO(IO1))
/SPI_COPI-IO0: U2.5 (DI(IO0)), U3.32 (SD_DATA_0), U4.5 (DI(IO0))
/SPI_SCK: RN1.3 (R3.1), U2.6 (CLK), U3.31 (SD_CLK), U4.6 (CLK)
/SPI_~CS: RN1.4 (R4.1), U3.30 (SD_CMD), U4.1 (~CS)
/SPI_~HLD-IO3: U2.7 (IO3), U3.29 (SD_DATA_3), U4.7 (IO3)
/SPI_~WP-IO2: U2.3 (IO2), U3.28 (SD_DATA_2), U4.3 (IO2)
/U0RXD: U3.40 (U0RXD), U7.26 (TXD)
/U0TXD: U3.41 (U0TXD), U7.25 (RXD)
/USB_N: J1.A7 (D-), J1.B7 (D-), U7.5 (D-)
/USB_P: J1.A6 (D+), J1.B6 (D+), U7.4 (D+)
/~CRESET: P31.1, Q1.3 (C), R1.1, RN1.1 (R1.1), SW2.1, SW2.2, U3.9 (CHIP_PU)
GND: AE1.2 (Shield), C1.2, C2.2, C3.1, C4.1, C5.2, C7.2, C9.2, C10.2, C11.2, C12.2, C13.2, C14.2, C15.2, C17.1, C18.2, C19.2, C20.2, J1.A1 (GND), J1.A12 (GND), J1.B1 (GND), J1.B12 (GND), J1.S1 (SHIELD), P25.1, R8.2, R17.1, R22.1, SW1.3, SW1.4, SW2.3, SW2.4, U2.4 (GND), U3.49 (GND), U4.4 (GND), U5.2 (MODE), U5.6 (GND), U5.7 (GND), U7.3 (GND), U7.29 (GND), Y1.2, Y1.4
unnamed: AE1.1 (A), C11.1, L2.2
unnamed: D3.2 (A), R13.1
unnamed: P16.1, U3.12 (32K_XP)
unnamed: P17.1, U3.13 (32K_XN)
unnamed: Q1.1 (B), R20.1
unnamed: Q2.1 (B), R21.1
unnamed: C16.2, C17.2, R15.1, U3.48 (CAP1)
unnamed: C16.1, R15.2, U3.47 (CAP2)
unnamed: C10.1, L2.1, U3.2 (LNA_IN)
unnamed: C3.2, U3.44 (XTAL_N), Y1.3
unnamed: C4.2, U3.45 (XTAL_P), Y1.1
unnamed: C6.2, R7.2, R8.1, U5.3 (FB)
unnamed: L1.1, U5.1 (SW)
unnamed: R16.1, R17.2, U7.8 (VBUS)
unnamed: R18.1, U7.9 (~RST)
unnamed: R22.2, U7.11 (~SUSPEND)
VBUS: C5.1, J1.A4 (VBUS), J1.A9 (VBUS), J1.B4 (VBUS), J1.B9 (VBUS), R16.2, U5.4 (EN), U5.5 (VIN)

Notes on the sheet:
Power Pins
Button
LEDs
USB to UART
ESP32-D0WDQ6
DCDC
Flash/RAM
Extra I/O - Programming
USB

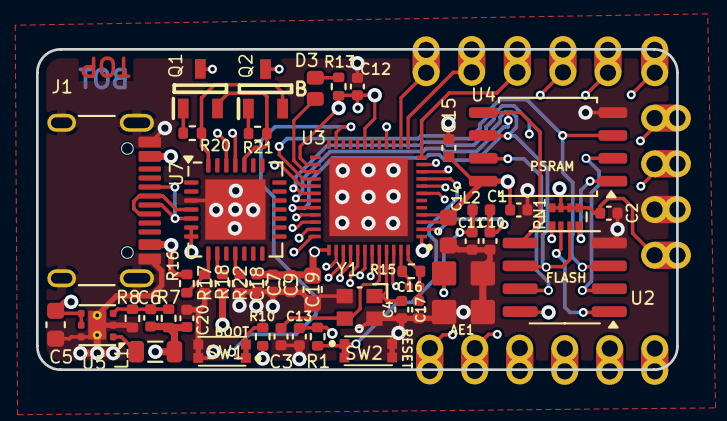
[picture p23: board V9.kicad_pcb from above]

Board: 4 copper layers, 35.6 x 17.8 mm, 63 parts (0 on the bottom side), 46 nets.

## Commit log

2024-11-02 *STABLE V.0.1*
    [3D_step file.step, ESP32-D0WD.step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]
2024-11-06 *V4 STABLE*
    [3D_step file.step, 47948-0001.stp, BoM.xlsx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]
2024-11-14 Versione 6
    [47948-0001.stp, BoM.xlsx, ECS-400-10-36B-CKY-TR.stp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]
2024-12-05 *V9 - STABLE*
    [V1-B_Cu.gbl, V1-B_Mask.gbs, V1-B_Paste.gbp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]
2024-12-06 Updated BOM file
    [V1.csv]
2024-12-06 updated PICK & PLACE file
    [V1-top-pos.csv]

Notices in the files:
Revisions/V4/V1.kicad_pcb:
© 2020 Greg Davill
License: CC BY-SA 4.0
